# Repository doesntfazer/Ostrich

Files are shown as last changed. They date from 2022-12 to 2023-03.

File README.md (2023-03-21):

# Ostrich

Ostrich

34 key keyboard based on RP2040 with canted MCU.

This keyboard was inspired by the Reviung34 keyboard.

You can find the qmk firmware [here](https://github.com/doesntfazer/Keyboard-Dweebs-Firmware-repository/tree/main/QMK/ostrich)

If you are interested in using VIAL instead, (This is a GUI for qmk). Then please go [here](https://github.com/doesntfazer/Keyboard-Dweebs-Firmware-repository/tree/main/VIAL-QMK/ostrich)

It is important to note, the 0.9 version of this keyboard keyboard is built with an mcp23017-e/so MCP chip instead of using diodes.  
This chip requires pull-up resistors. Since this was meant to use an OLED, it just borrows the one built into the SSD1306. If you decide you don't want an OLED, you will need to solder pull up resistors on GP0 and GP1. (4.7k have been sufficient in my testing)

If you are using the 1.0 or later versions of this keyboard, the keyboards will use diodes, and you won't have to worry about it.

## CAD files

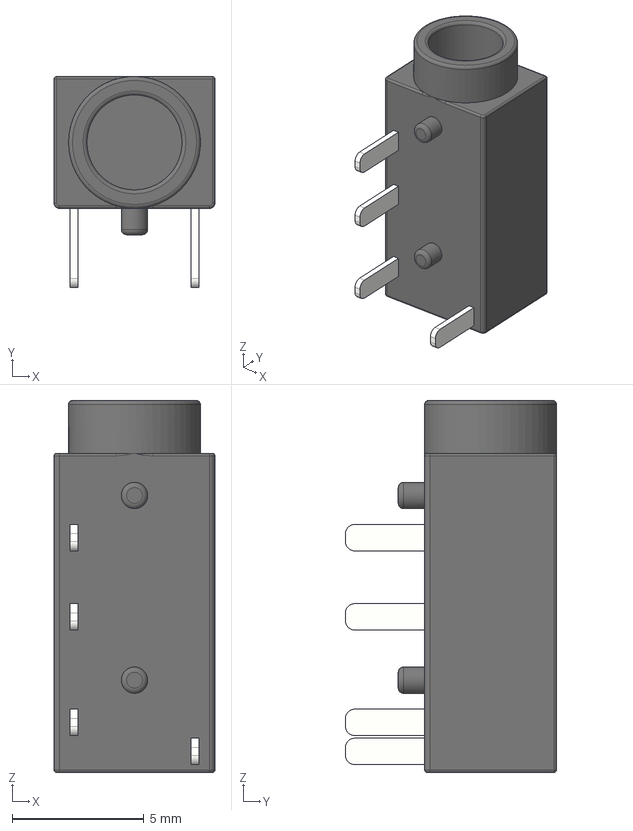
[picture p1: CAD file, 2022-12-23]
components/Keebio-Parts.pretty-master/3dmodels/PJ-320A.step
6.10 x 8.00 x 14.1 mm

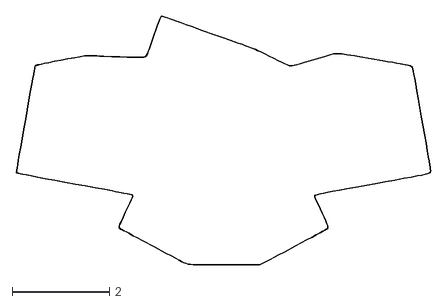
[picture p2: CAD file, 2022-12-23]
dxf/edge.dxf
8.55 x 5.13

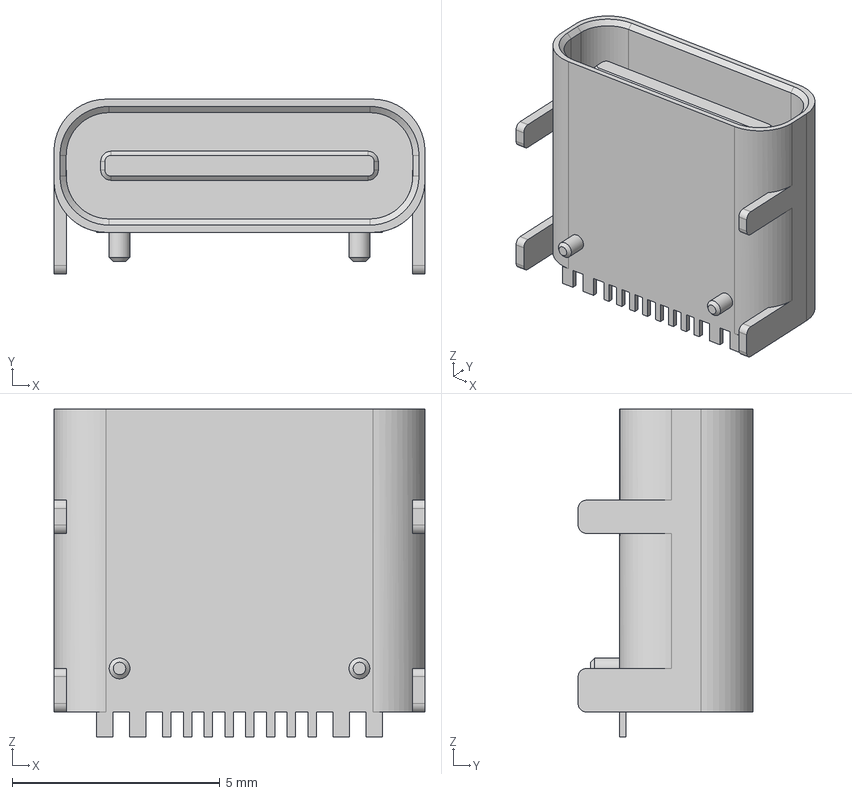
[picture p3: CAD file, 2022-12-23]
components/Keebio-Parts.pretty-master/3dmodels/HRO TYPE-C-31-M-12.step
8.94 x 4.21 x 7.90 mm

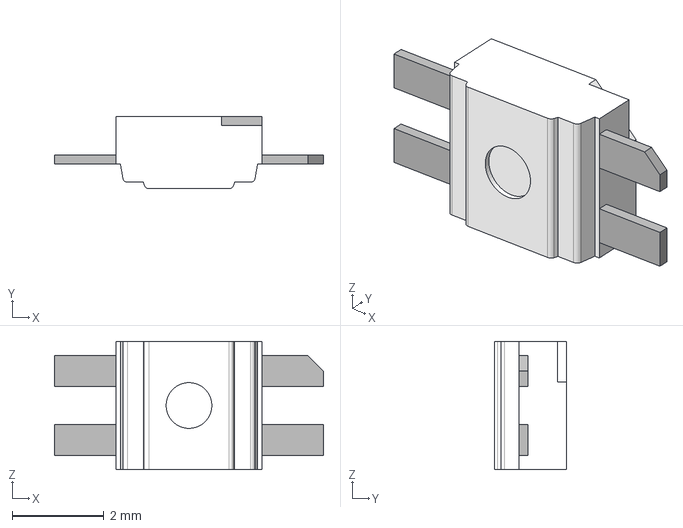
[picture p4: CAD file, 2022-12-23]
components/Keebio-Parts.pretty-master/3dmodels/SK6812MINI-E v1.step
5.88 x 1.58 x 2.80 mm

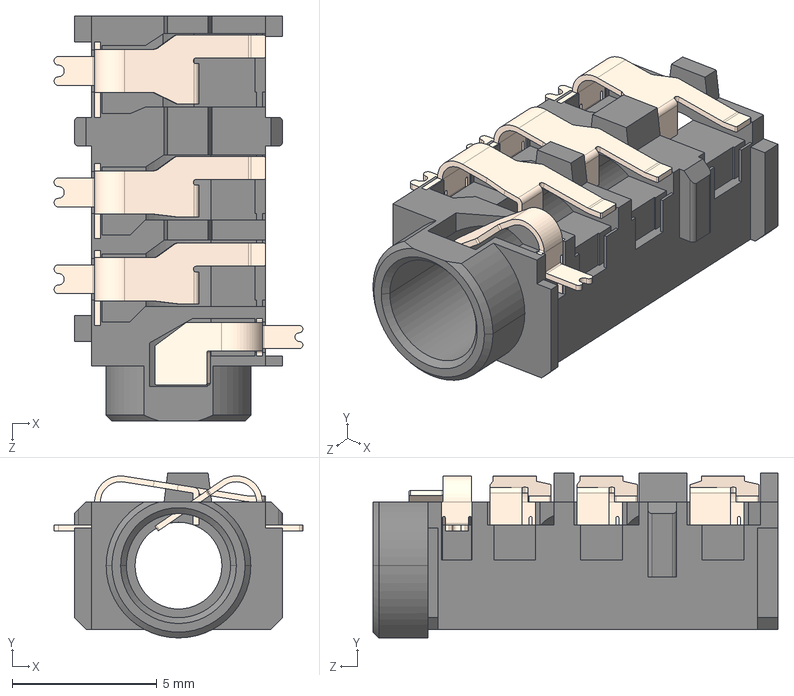
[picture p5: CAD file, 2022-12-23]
components/Keebio-Parts.pretty-master/3dmodels/CUI_SJ-43614-SMT-TR.step
8.60 x 5.70 x 14.0 mm

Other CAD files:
components/KiCad-RP-Pico-main/SketchUp Model/Pico.skp

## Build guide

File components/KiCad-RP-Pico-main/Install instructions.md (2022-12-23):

# Install instructions

## 1. Copy the files locally

Copy the `RP-Pico Libraries` folder wherever you like on your computer.

## 2. Install the Raspberry Pi Pico board schema symbol

Use the `KiCad | Preferences | Manage Symbol Libraries...` command to manage the symbol library:



then select the global tab and click on the folder button:



navigate to the `RP-Pico Libraries` folder, select the `MCU_RaspberryPi_and_Boards.kicad_sym` file and open it:



et voilà, the first step is completed:



You can now close the symbol libraries manager window.

## 3. Install the Raspberry Pi Pico board footprint

You can use a similar approach to add the footprint to the footprint libraries manager, but I've found some issues that I've solved using the footprint editor, so here are the steps I suggest you to follow:

Open the footprint editor



wait for the footprints to load... then use the `File | Add Library` command:



confirm the `Global` choice:



and select the `MCU_RaspberriPi_and_Boards.pretty` folder (yes, the folder represent a footprint library on KiCad):



Now the library is installed on KiCad with the Raspberry Pi Pico footprint (double click on it to see it on the editor pane):



Don't close the windows as the next step start from here.

## 4. Install the Raspberry Pi Pico board footprint 3D visual

If not already open, open the the footprint editor

symbol library manager

double click on the `RPi_Pico_SMD_TH` footprint from the `MCU_RaspberriPi_and_Boards` library and then click on the `Footprint properties` icon:



In the footprint properties window, first select the `3D Settings` tab. Please note that the preview shows only the PCB board with the footprint added on step 3, without any 3D representation of the Raspberry Pi Pico board. Now click on the folder icon to add the 3D model:



Navigate to the `RP-Pico Libraries` folder, select the `Pico.wrl` file and wait until the model is shown in the right panel, then confirm with OK:



The model is already scaled and translated to match the footprint:



now close the `Footprint Properties` window, and the `Footprint Editor`, obviously saving the changes.

## Conclusion

Now that you've installed the schema and footprint and added the 3D model to the footprint, you can use the Raspberry Pi Pico board on your KiCad projects.

I've also added a test KiCad Project on the `Test` folder, that you can use to see an example of it.

Have fun!

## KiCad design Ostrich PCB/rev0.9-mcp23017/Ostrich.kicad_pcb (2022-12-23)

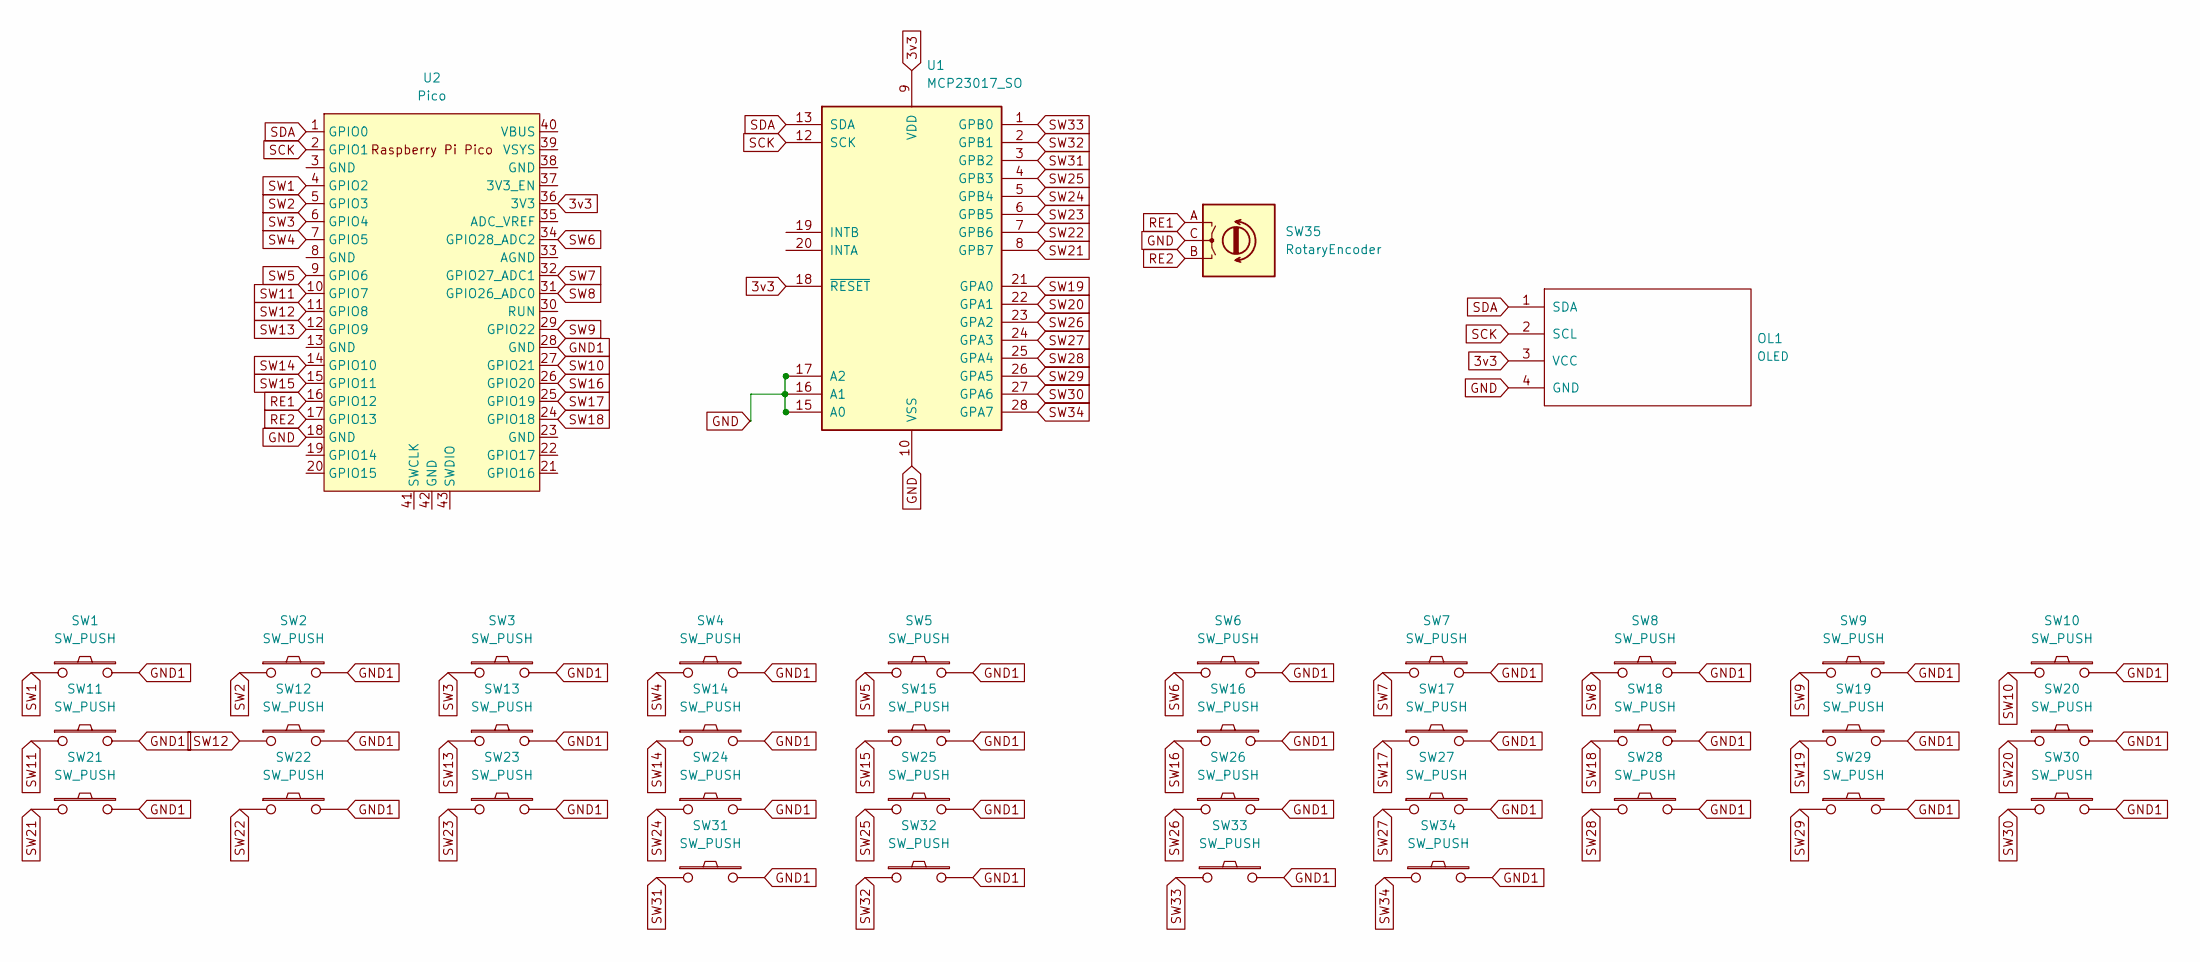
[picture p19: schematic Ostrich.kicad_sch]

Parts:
OL1: OLED; OLED_v2
SW1, SW2, SW3, SW4, SW5, SW6, SW7, SW8, SW9, SW10, SW11, SW12, SW13, SW14, SW15, SW16, SW17, SW18, SW19, SW20, SW21, SW22, SW23, SW24, SW25, SW26, SW27, SW28, SW29, SW30, SW31, SW32, SW33, SW34: SW_PUSH; CherryMX_Choc_1u-w3
SW35: RotaryEncoder; RotaryEncoder_Alps_EC12E_Vertical_H20mm
U1: MCP23017_SO; SOIC-28W_7.5x17.9mm_P1.27mm
U2: Pico; RPi_Pico_SMD_TH

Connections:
3v3: OL1.3 (VCC), U1.9 (VDD), U1.18 (~RESET), U2.36 (3V3)
GND: OL1.4 (GND), SW35.C, U1.10 (VSS), U1.15 (A0), U1.16 (A1), U1.17 (A2), U2.18 (GND)
GND1: SW1.2, SW2.2, SW3.2, SW4.2, SW5.2, SW6.2, SW7.2, SW8.2, SW9.2, SW10.2, SW11.2, SW12.2, SW13.2, SW14.2, SW15.2, SW16.2, SW17.2, SW18.2, SW19.2, SW20.2, SW21.2, SW22.2, SW23.2, SW24.2, SW25.2, SW26.2, SW27.2, SW28.2, SW29.2, SW30.2, SW31.2, SW32.2, SW33.2, SW34.2, U2.28 (GND)
RE1: SW35.A, U2.16 (GPIO12)
RE2: SW35.B, U2.17 (GPIO13)
SCK: OL1.2 (SCL), U1.12 (SCK), U2.2 (GPIO1)
SDA: OL1.1 (SDA), U1.13 (SDA), U2.1 (GPIO0)
SW1: SW1.1, U2.4 (GPIO2)
SW2: SW2.1, U2.5 (GPIO3)
SW3: SW3.1, U2.6 (GPIO4)
SW4: SW4.1, U2.7 (GPIO5)
SW5: SW5.1, U2.9 (GPIO6)
SW6: SW6.1, U2.34 (GPIO28_ADC2)
SW7: SW7.1, U2.32 (GPIO27_ADC1)
SW8: SW8.1, U2.31 (GPIO26_ADC0)
SW9: SW9.1, U2.29 (GPIO22)
SW10: SW10.1, U2.27 (GPIO21)
SW11: SW11.1, U2.10 (GPIO7)
SW12: SW12.1, U2.11 (GPIO8)
SW13: SW13.1, U2.12 (GPIO9)
SW14: SW14.1, U2.14 (GPIO10)
SW15: SW15.1, U2.15 (GPIO11)
SW16: SW16.1, U2.26 (GPIO20)
SW17: SW17.1, U2.25 (GPIO19)
SW18: SW18.1, U2.24 (GPIO18)
SW19: SW19.1, U1.21 (GPA0)
SW20: SW20.1, U1.22 (GPA1)
SW21: SW21.1, U1.8 (GPB7)
SW22: SW22.1, U1.7 (GPB6)
SW23: SW23.1, U1.6 (GPB5)
SW24: SW24.1, U1.5 (GPB4)
SW25: SW25.1, U1.4 (GPB3)
SW26: SW26.1, U1.23 (GPA2)
SW27: SW27.1, U1.24 (GPA3)
SW28: SW28.1, U1.25 (GPA4)
SW29: SW29.1, U1.26 (GPA5)
SW30: SW30.1, U1.27 (GPA6)
SW31: SW31.1, U1.3 (GPB2)
SW32: SW32.1, U1.2 (GPB1)
SW33: SW33.1, U1.1 (GPB0)
SW34: SW34.1, U1.28 (GPA7)

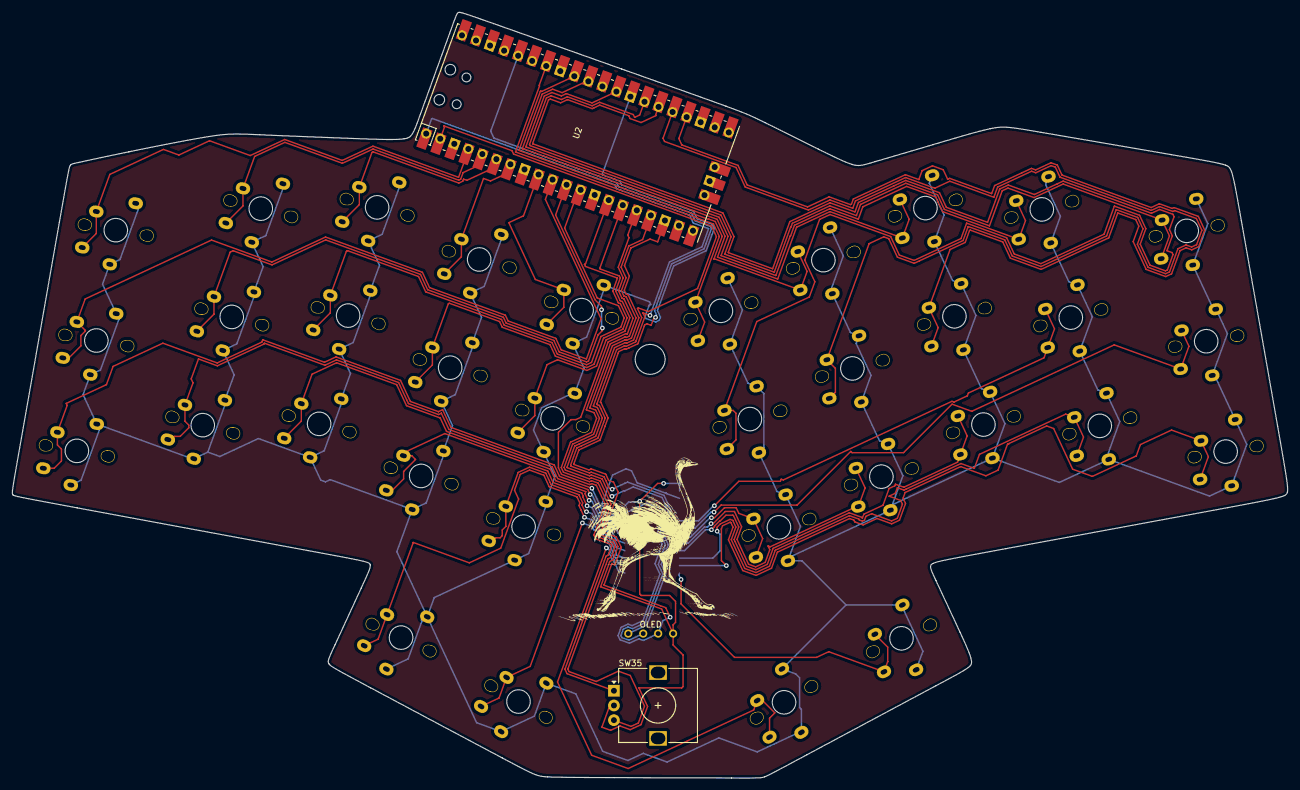
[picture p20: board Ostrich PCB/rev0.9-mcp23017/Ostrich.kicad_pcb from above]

Board: 2 copper layers, 216.8 x 130.2 mm, 38 parts (1 on the bottom side), 41 nets.

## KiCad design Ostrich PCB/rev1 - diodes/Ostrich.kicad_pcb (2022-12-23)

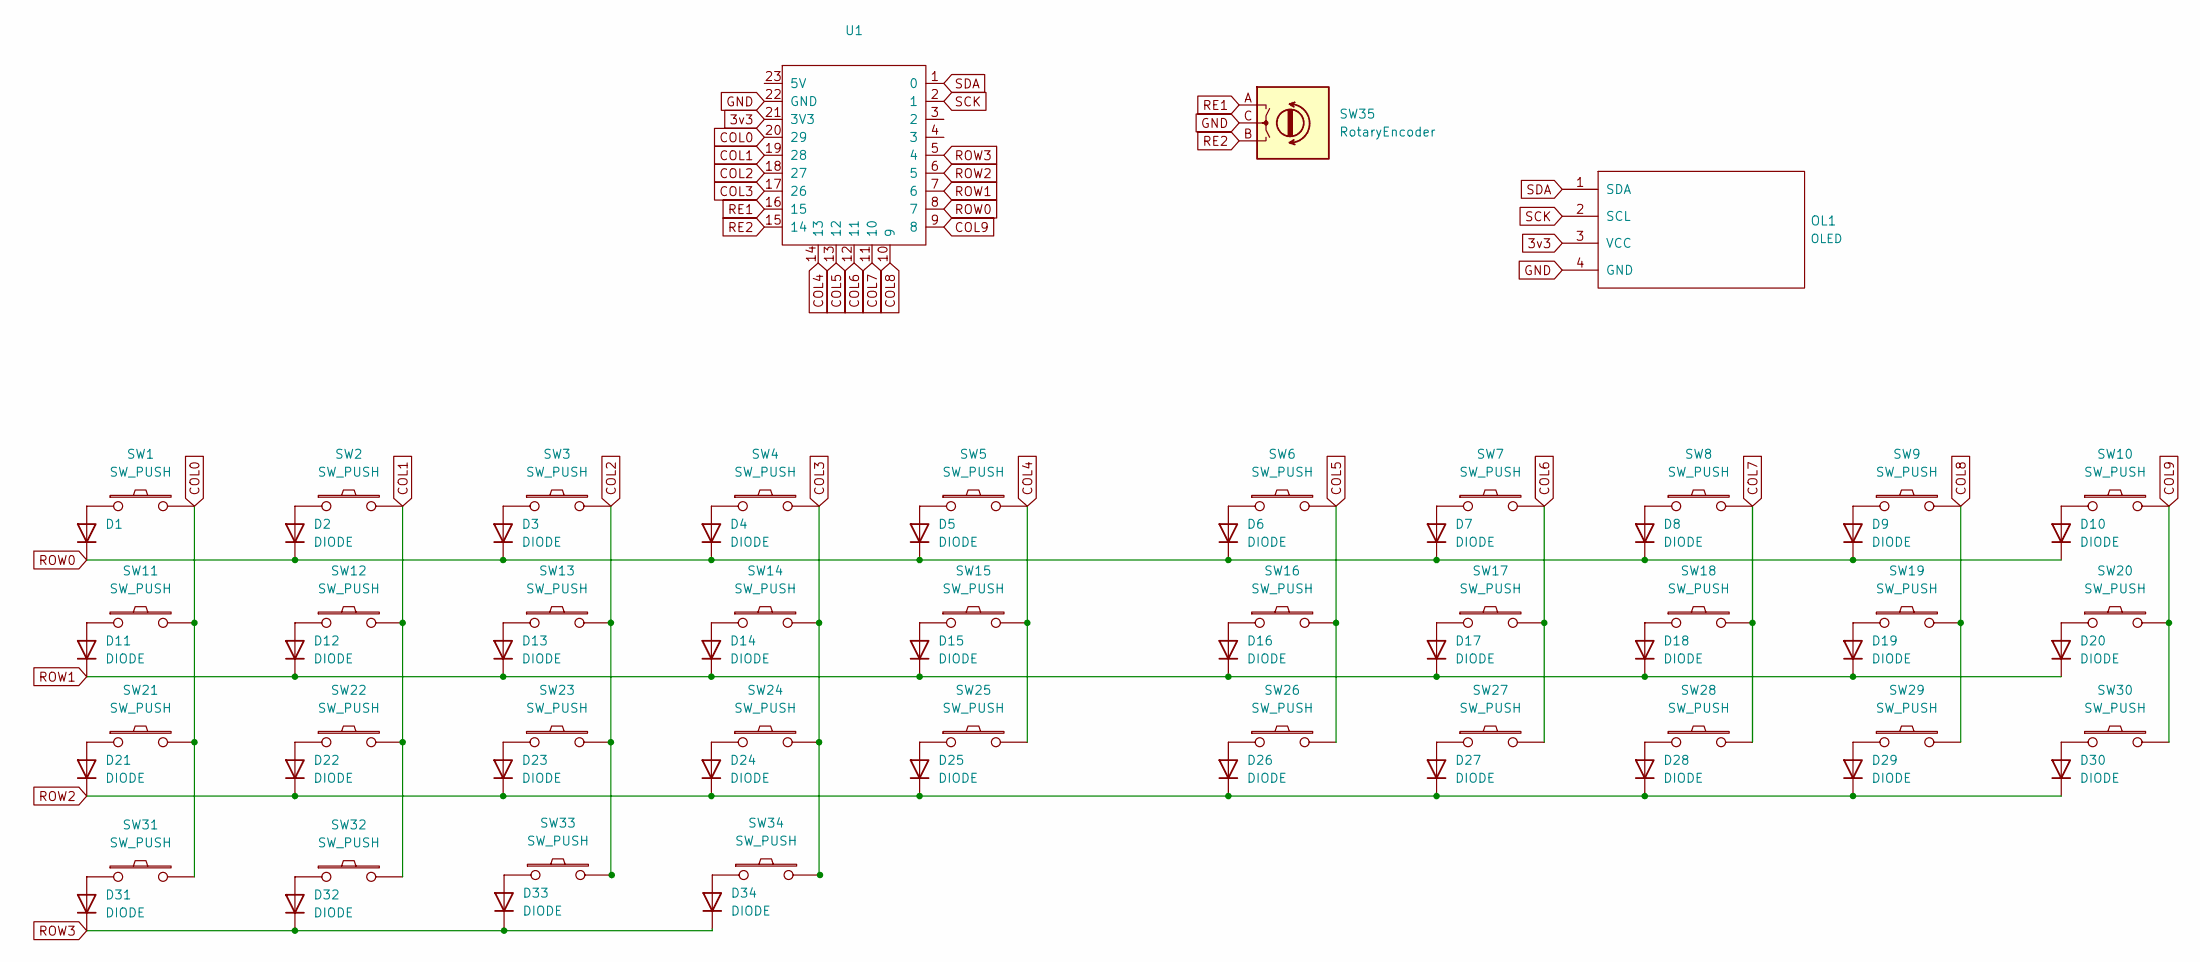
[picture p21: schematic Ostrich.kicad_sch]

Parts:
D1: (no value)
D2, D3, D4, D5, D6, D7, D8, D9, D10, D11, D12, D13, D14, D15, D16, D17, D18, D19, D20, D21, D22, D23, D24, D25, D26, D27, D28, D29, D30, D31, D32, D33, D34: DIODE
OL1: OLED; OLED_v2
SW1, SW2, SW3, SW4, SW5, SW6, SW7, SW8, SW9, SW10, SW11, SW12, SW13, SW14, SW15, SW16, SW17, SW18, SW19, SW20, SW21, SW22, SW23, SW24, SW25, SW26, SW27, SW28, SW29, SW30, SW31, SW32, SW33, SW34: SW_PUSH; CherryMX_Choc_1u-w3
SW35: RotaryEncoder; RotaryEncoder_Alps_EC12E_Vertical_H20mm
U1: (no value)

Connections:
3v3: OL1.3 (VCC), U1.21 (3V3)
COL0: SW1.2, SW11.2, SW21.2, SW31.2, U1.20 (29)
COL1: SW2.2, SW12.2, SW22.2, SW32.2, U1.19 (28)
COL2: SW3.2, SW13.2, SW23.2, SW33.2, U1.18 (27)
COL3: SW4.2, SW14.2, SW24.2, SW34.2, U1.17 (26)
COL4: SW5.2, SW15.2, SW25.2, U1.14 (13)
COL5: SW6.2, SW16.2, SW26.2, U1.13 (12)
COL6: SW7.2, SW17.2, SW27.2, U1.12 (11)
COL7: SW8.2, SW18.2, SW28.2, U1.11 (10)
COL8: SW9.2, SW19.2, SW29.2, U1.10 (9)
COL9: SW10.2, SW20.2, SW30.2, U1.9 (8)
GND: OL1.4 (GND), SW35.C, U1.22 (GND)
unnamed: D32.1 (A), SW32.1
unnamed: D1.1 (A), SW1.1
unnamed: D2.1 (A), SW2.1
unnamed: D3.1 (A), SW3.1
unnamed: D4.1 (A), SW4.1
unnamed: D5.1 (A), SW5.1
unnamed: D6.1 (A), SW6.1
unnamed: D7.1 (A), SW7.1
unnamed: D8.1 (A), SW8.1
unnamed: D9.1 (A), SW9.1
unnamed: D10.1 (A), SW10.1
unnamed: D11.1 (A), SW11.1
unnamed: D12.1 (A), SW12.1
unnamed: D13.1 (A), SW13.1
unnamed: D14.1 (A), SW14.1
unnamed: D15.1 (A), SW15.1
unnamed: D16.1 (A), SW16.1
unnamed: D17.1 (A), SW17.1
unnamed: D18.1 (A), SW18.1
unnamed: D19.1 (A), SW19.1
unnamed: D20.1 (A), SW20.1
unnamed: D21.1 (A), SW21.1
unnamed: D22.1 (A), SW22.1
unnamed: D23.1 (A), SW23.1
unnamed: D24.1 (A), SW24.1
unnamed: D25.1 (A), SW25.1
unnamed: D26.1 (A), SW26.1
unnamed: D27.1 (A), SW27.1
unnamed: D28.1 (A), SW28.1
unnamed: D29.1 (A), SW29.1
unnamed: D30.1 (A), SW30.1
unnamed: D31.1 (A), SW31.1
unnamed: D33.1 (A), SW33.1
unnamed: D34.1 (A), SW34.1
RE1: SW35.A, U1.16 (15)
RE2: SW35.B, U1.15 (14)
ROW0: D1.2 (K), D2.2 (K), D3.2 (K), D4.2 (K), D5.2 (K), D6.2 (K), D7.2 (K), D8.2 (K), D9.2 (K), D10.2 (K), U1.8 (7)
ROW1: D11.2 (K), D12.2 (K), D13.2 (K), D14.2 (K), D15.2 (K), D16.2 (K), D17.2 (K), D18.2 (K), D19.2 (K), D20.2 (K), U1.7 (6)
ROW2: D21.2 (K), D22.2 (K), D23.2 (K), D24.2 (K), D25.2 (K), D26.2 (K), D27.2 (K), D28.2 (K), D29.2 (K), D30.2 (K), U1.6 (5)
ROW3: D31.2 (K), D32.2 (K), D33.2 (K), D34.2 (K), U1.5 (4)
SCK: OL1.2 (SCL), U1.2 (1)
SDA: OL1.1 (SDA), U1.1 (0)

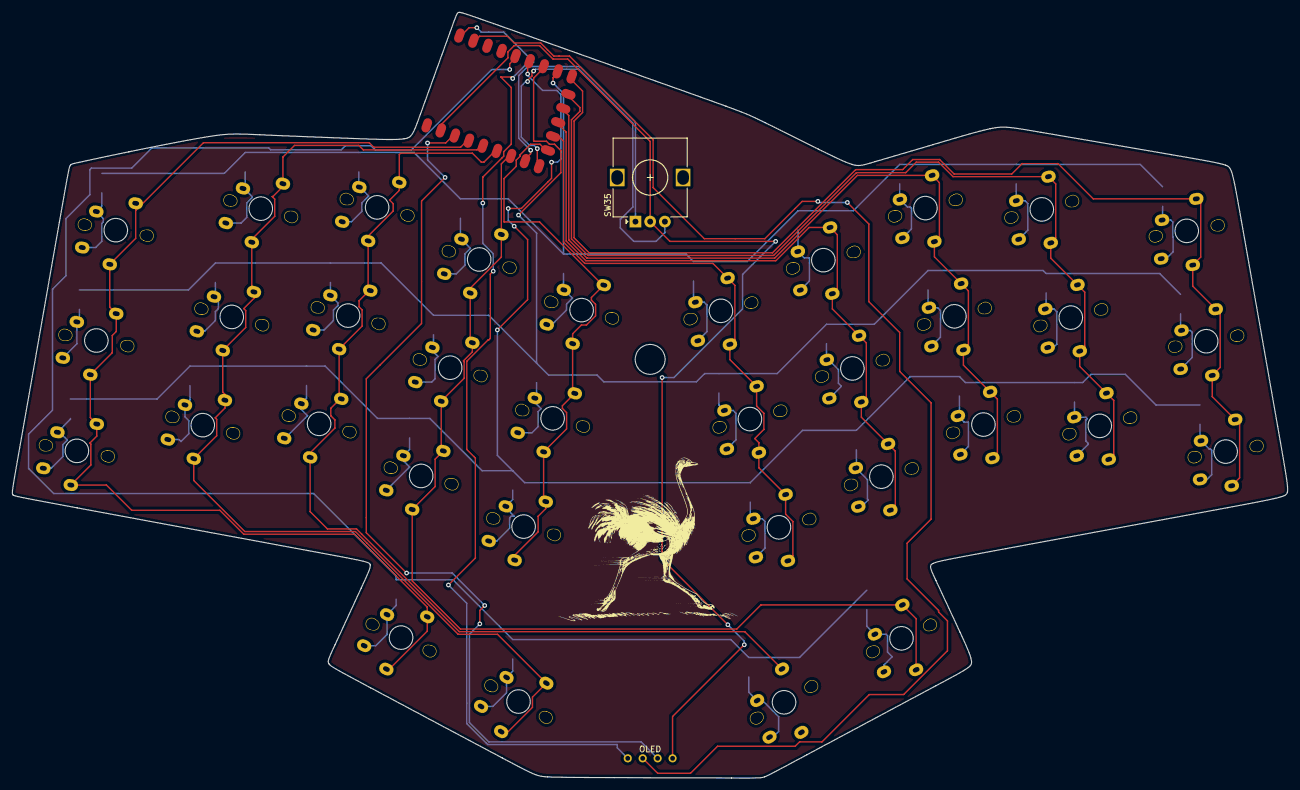
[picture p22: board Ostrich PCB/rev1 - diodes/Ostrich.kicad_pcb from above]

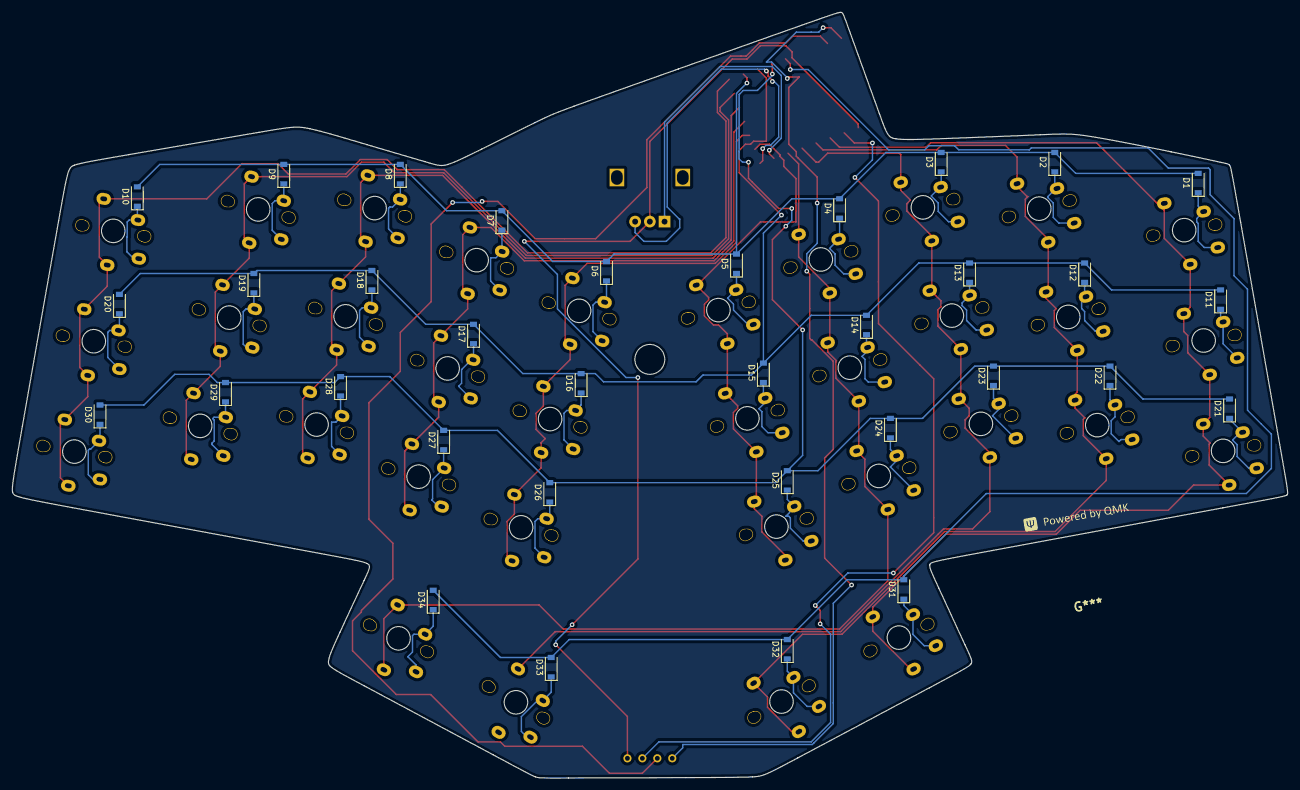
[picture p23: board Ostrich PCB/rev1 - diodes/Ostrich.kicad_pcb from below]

Board: 2 copper layers, 216.8 x 130.2 mm, 71 parts (34 on the bottom side), 54 nets.

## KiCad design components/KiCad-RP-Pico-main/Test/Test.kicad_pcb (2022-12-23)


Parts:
J1, J2: Conn_01x20; PinSocket_1x20_P1.00mm_Vertical
J3: Conn_01x03; PinSocket_1x03_P1.00mm_Vertical
U1: Pico; RPi_Pico_SMD_TH

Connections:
GND: J1.3, J1.8, J1.13, J1.18, J2.3, J2.13, J2.18, J3.2, U1.3 (GND), U1.8 (GND), U1.13 (GND), U1.18 (GND), U1.23 (GND), U1.28 (GND), U1.38 (GND), U1.42 (GND)
unnamed: J1.1, U1.1 (GPIO0)
unnamed: J1.2, U1.2 (GPIO1)
unnamed: J1.4, U1.4 (GPIO2)
unnamed: J1.5, U1.5 (GPIO3)
unnamed: J1.6, U1.6 (GPIO4)
unnamed: J1.7, U1.7 (GPIO5)
unnamed: J1.9, U1.9 (GPIO6)
unnamed: J1.10, U1.10 (GPIO7)
unnamed: J1.11, U1.11 (GPIO8)
unnamed: J1.12, U1.12 (GPIO9)
unnamed: J1.14, U1.14 (GPIO10)
unnamed: J1.15, U1.15 (GPIO11)
unnamed: J1.16, U1.16 (GPIO12)
unnamed: J1.17, U1.17 (GPIO13)
unnamed: J1.19, U1.19 (GPIO14)
unnamed: J1.20, U1.20 (GPIO15)
unnamed: J2.1, U1.40 (VBUS)
unnamed: J2.2, U1.39 (VSYS)
unnamed: J2.4, U1.37 (3V3_EN)
unnamed: J2.5, U1.36 (3V3)
unnamed: J2.6, U1.35 (ADC_VREF)
unnamed: J2.7, U1.34 (GPIO28_ADC2)
unnamed: J2.8, U1.33 (AGND)
unnamed: J2.9, U1.32 (GPIO27_ADC1)
unnamed: J2.10, U1.31 (GPIO26_ADC0)
unnamed: J2.11, U1.30 (RUN)
unnamed: J2.12, U1.29 (GPIO22)
unnamed: J2.14, U1.27 (GPIO21)
unnamed: J2.15, U1.26 (GPIO20)
unnamed: J2.16, U1.25 (GPIO19)
unnamed: J2.17, U1.24 (GPIO18)
unnamed: J2.19, U1.22 (GPIO17)
unnamed: J2.20, U1.21 (GPIO16)
unnamed: J3.1, U1.43 (SWDIO)
unnamed: J3.3, U1.41 (SWCLK)


Board: 2 copper layers, 43.0 x 65.0 mm, 4 parts (0 on the bottom side), 36 nets.
